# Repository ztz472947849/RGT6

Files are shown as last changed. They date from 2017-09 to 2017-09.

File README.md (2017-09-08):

# Embedded Glue

A minimal system runs MicroPython using STM32F405RGT6

Designed in KiCAD, free to use in any application.

# Pics

PCB preview in KiCAD
</br>

</br>
Actual PCB
</br>

</br>
And the size of its stencil
</br>


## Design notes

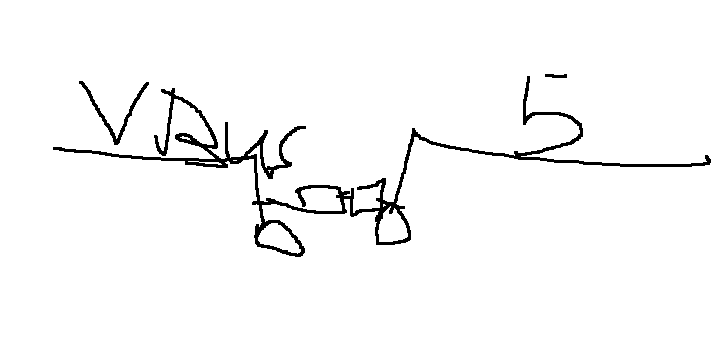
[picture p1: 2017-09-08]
RGT6_core_module/vbus.png

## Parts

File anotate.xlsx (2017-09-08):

sch | CPU | function | drop
j1 |  | a3v3 | C6 | uart/adc
j2 |  | usb_otg | C7
j3 |  | IO | A0 | uart
j4 |  | gnd | A1
j5 |  | vbus | A4 | SPI/DAC
j6 |  | 3v3 | A5
j7 |  | sd | A6
j8 |  | sd | A7
j9 |  | sd | pybaord X area bottom
j10 |  | sd | C4 | ADC only
j11 |  | IO | C5
j12 |  | IO | B0
j13 |  | IO | B1
j14 |  | boot0
j15 |  | boot1
j16 |  | adc
j17 |  | x
j18 |  | sd
j19 |  | sd
j20 |  | adc
j21 |  | adc
j22 |  | adc
j23 |  | IO
j24 |  | IO
j25 |  | SCL1
j26 |  | SDA1
j27 |  | SCL2
j28 |  | SDA2
j29 |  | IO
j30 |  | IO
j31 |  | uart TX
j32 |  | uart RX
j33 |  | uart2 TX
j34 |  | uart2 RX
j35 |  | uart3 TX
j36 |  | uart3 RX
j37 |  | DAC
j38 |  | DAC
j39 |  | IO
j40 |  | IO
j41 |  | sd
j42 |  | jtag
j43 |  | jtag
j44 |  | jtag
j45 |  | IO

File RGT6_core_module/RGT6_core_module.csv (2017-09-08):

Reference | Value | Footprint | general search | backup link
U1 | STM32F405RGTx | Housings_QFP:LQFP-64_10x10mm_Pitch0.5mm | http://uk.rs-online.com/web/p/microcontrollers/7468217/ | http://uk.farnell.com/search?st=STM32F405RGT
R2 | 100k | Resistors_SMD:R_0603 | http://uk.farnell.com/yageo/rc0603fr-07100kl/res-thick-film-100k-1-0-1w-0603/dp/2133868
C5 | 2u2 | Capacitors_SMD:C_0603 | http://uk.farnell.com/c/passive-components/capacitors/ceramic-capacitors/smd-ceramic-multilayer-mlcc-capacitors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
C6 | 2u2 | Capacitors_SMD:C_0603 | ¡ü
Y1 | 8Mhz | Crystals:Crystal_SMD_0603-2pin_6.0x3.5mm | http://uk.farnell.com/w/c/crystals-oscillators/crystals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
C3 | 18p | Capacitors_SMD:C_0603 | http://uk.farnell.com/multicomp/mc0603n180j500ct/cap-mlcc-c0g-np0-18pf-50v-0603/dp/1759056
C4 | 18p | Capacitors_SMD:C_0603 | ¡ü
L1 | 1k | Inductors_SMD:L_0603 | http://uk.farnell.com/c/passive-components/emc-rfi-suppression/ferrites-ferrite-assortments/ferrite-beads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
C8 | 100n | Capacitors_SMD:C_0603 | http://uk.farnell.com/walsin/0603b104k500ct/capacitor-mlcc-x7r-0-1uf-50v-0603/dp/2496834
C7 | 4u7 | Capacitors_SMD:C_0603 | http://uk.farnell.com/yageo/cc0603mrx5r5bb475/ceramic-capacitor-4-7uf-6-3v-x5r/dp/1817928
R7 | 100k | Resistors_SMD:R_0603 | http://uk.farnell.com/yageo/rc0603fr-07100kl/res-thick-film-100k-1-0-1w-0603/dp/2133868
SW1 | SW_Push | Buttons_Switches_SMD:SW_SPST_B3U-1000P | https://www.omron.com/ecb/products/pdf/en-b3u.pdf
R8 | 4k7 | Resistors_SMD:R_0603 | http://uk.farnell.com/w/c/passive-components/resistors-fixed-value/chip-smd-resistors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
R9 | 4k7 | Resistors_SMD:R_0603 | ¡ü
R10 | 4k7 | Resistors_SMD:R_0603 | ¡ü
R11 | 4k7 | Resistors_SMD:R_0603 | ¡ü
R12 | 4k7 | Resistors_SMD:R_0603 | ¡ü
J2 | USB_OTG | Connectors_USB:USB_Micro-B_Vertical_Molex | http://uk.farnell.com/global-connector-technology/usb3105-30-a/micro-usb-2-0-type-ab-receptacle/dp/2293775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
R4 | 560 | Resistors_SMD:R_0603 | http://uk.farnell.com/w/c/passive-components/resistors-fixed-value/chip-smd-resistors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
R5 | 22 | Resistors_SMD:R_0603 | http://uk.farnell.com/w/c/passive-components/resistors-fixed-value/chip-smd-resistors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
R6 | 22 | Resistors_SMD:R_0603 | ¡ü
R3 | 560 | Resistors_SMD:R_0603 | http://uk.farnell.com/w/c/passive-components/resistors-fixed-value/chip-smd-resistors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
Y2 | 32.768khz | Crystals:Crystal_SMD_0603-2pin_6.0x3.5mm | http://uk.farnell.com/c/crystals-oscillators/crystals?frequency-nom=32.768khz
C1 | 2p2 | Capacitors_SMD:C_0603 | http://uk.farnell.com/multicomp/mcmt18n2r2c160ct/cap-mlcc-c0g-np0-2-2pf-16v-0603/dp/1856096
C2 | 2p2 | Capacitors_SMD:C_0603 | ¡ü
D1 | D1 | ceremic diode | http://uk.farnell.com/c/semiconductors-discretes/diodes/small-signal-diodes
 |  | WS2812B | https://item.taobao.com/item.htm?id=43732789425&ns=1&abbucket=16
R1 | 300ohm | R 0603 | http://uk.farnell.com/w/c/passive-components/resistors-fixed-value/chip-smd-resistors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
R | 300ohm | R 0603 | ¡ü
U2 | MCP1703A-4002_SOT23 | TO_SOT_Packages_SMD:SOT-23 | not found on Farnell/RS
C9 | 1uf | Capacitors_SMD:C_0603 | http://uk.farnell.com/w/c/passive-components/capacitors/ceramic-capacitors/prl/results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
R13 | 220 | Resistors_SMD:R_0603 | http://uk.farnell.com/w/c/passive-components/resistors-fixed-value/chip-smd-resistors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

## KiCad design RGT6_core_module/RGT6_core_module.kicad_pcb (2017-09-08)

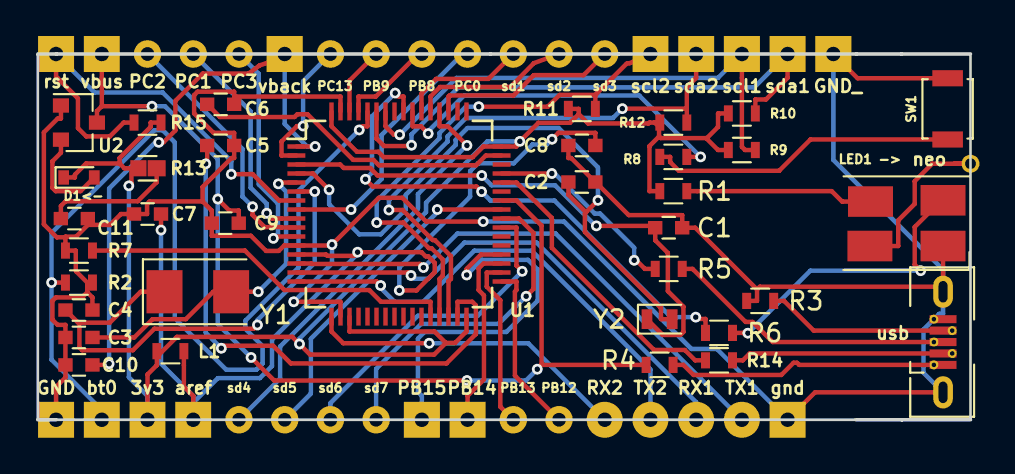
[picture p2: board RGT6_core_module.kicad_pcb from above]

Board: 2 copper layers, 51.8 x 20.3 mm, 71 parts (0 on the bottom side), 54 nets.

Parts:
3v3: CONN_01X01_FEMALE; SolderWirePad_single_0-8mmDrill
C1, C2: 2p2; C_0603
C3, C4: 18p; C_0603
C5, C6: 2u2; C_0603
C7: 4u7; C_0603
C8: 100n; C_0603
C9: 1uF; C_0603
C10, C11: 100nF; C_0603
D1<-: DIODE; D_0603
GND: GND; SolderWirePad_single_0-8mmDrill
GND_: GND; SolderWirePad_single_0-8mmDrill
L1: 1k; L_0603
LED1 ->: WS2812B; ws2812_big-pad
PB8, PB9, PB12: CONN_01X01_FEMALE; testpoint
PB13, PB14, PB15: jtag; testpoint
PC0, PC1, PC2, PC3: ADCs; testpoint
PC13: do not use; testpoint
R1, R14: 300; R_0603
R2, R7: 100k; R_0603
R3, R4: 560; R_0603
R5, R6: 22; R_0603
R8, R9, R10, R11, R12, R15: 4k7; R_0603
R13: 220; R_0603_short
RX1: uart4 RX; SolderWirePad_single_0-8mmDrill
RX2: usart RX; SolderWirePad_single_0-8mmDrill
SW1: SW_Push; SW_SPST_B3U-1000P
TX1: uart4 TX; SolderWirePad_single_0-8mmDrill
TX2: usart TX; SolderWirePad_single_0-8mmDrill
U1: STM32F405RGTx; LQFP-64_10x10mm_Pitch0.5mm
U2: MCP1703A-4002_SOT23; SOT-23
Y1: 8Mhz; Crystal_SMD_5032-2pin_5.0x3.2mm
Y2: 32.768khz; Crystal_SMD_2012-2pin_2.0x1.2mm
aref: a3v3; testpoint
bt0: CONN_01X01_FEMALE; SolderWirePad_single_0-8mmDrill
gnd: GND; SolderWirePad_single_0-8mmDrill
neo: neo_out; SolderWirePad_single_0-8mmDrill
rst: CONN_01X01_FEMALE; SolderWirePad_single_0-8mmDrill
scl1, scl2: CONN_01X01_FEMALE; SolderWirePad_single_0-8mmDrill
sd1, sd2, sd3, sd4, sd5, sd6, sd7: CONN_01X01_FEMALE; testpoint
sda1, sda2: CONN_01X01_FEMALE; SolderWirePad_single_0-8mmDrill
usb: USB_OTG; my_usb
vback: CONN_01X01_FEMALE; SolderWirePad_single_0-8mmDrill
vbus: CONN_01X01_FEMALE; SolderWirePad_single_0-8mmDrill

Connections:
3.3v: 3v3.1, D1<-.1, L1.2, R1.1, R9.1, R10.1, R11.1, R12.1, R13.1, R15.2, U1.19, U1.32, U1.48, U1.64
A3v3: C7.2, C8.2, L1.1, U1.13, aref.1
D+: R5.1, U1.45
D-: R6.1, U1.44
unnamed: C1.1, U1.3, Y2.1
unnamed: C2.1, U1.4, Y2.2
unnamed: C3.2, U1.5, Y1.2
unnamed: C4.1, U1.6, Y1.1
unnamed: C5.1, U1.31
unnamed: C6.1, U1.47
unnamed: D1<-.2, U2.2
unnamed: R4.2, usb.1
unnamed: R6.2, usb.2
unnamed: R5.2, usb.3
unnamed: R3.1, usb.4
unnamed: LED1 ->.1, R1.2
unnamed: LED1 ->.4, R14.1
unnamed: R8.1, SW1.1
unnamed: R8.2, U1.55
PA0: TX1.1, U1.14
PA1: RX1.1, U1.15
PA2: TX2.1, U1.16
PA3: RX2.1, U1.17
PA8_sd: U1.41, sd5.1
PB4: R14.2, U1.56
PB8: PB8.1, U1.61
PB9: PB9.1, U1.62
PB12: PB12.1, U1.33
PB13: PB13.1, U1.34
PB14: PB14.1, U1.35
PB15: PB15.1, U1.36
PC0: PC0.1, U1.8
PC1: PC1.1, U1.9
PC2: PC2.1, U1.10
PC3: PC3.1, U1.11
PC8_sd: U1.39, sd6.1
PC9_sd: U1.40, sd7.1
PC10_sd: U1.51, sd3.1
PC11_sd: U1.52, sd4.1
PC12_sd: U1.53, sd2.1
PC13: PC13.1, U1.2
PD2_sd: U1.54, sd1.1
SCL1: R9.2, U1.58, scl1.1
SCL2: R11.2, U1.29, scl2.1
SDA1: R10.2, U1.59, sda1.1
SDA2: R12.2, U1.30, sda2.1
boot0: R2.1, U1.60, bt0.1
boot1: R7.2, U1.28
gnd: C1.2, C2.2, C3.1, C4.2, C5.2, C6.2, C7.1, C8.1, C9.1, C10.2, C11.2, GND.1, GND_.1, LED1 ->.3, R2.2, R3.2, R7.1, SW1.2, U1.12, U1.18, U1.63, U2.1, gnd.1, usb.5, usb.6
neo_out: LED1 ->.2, neo.1
rst: R15.1, U1.7, rst.1
v-battery: C11.1, R13.2
vbackup: C10.1, U1.1, vback.1
vbus: C9.2, R4.1, U1.42, U2.3, vbus.1

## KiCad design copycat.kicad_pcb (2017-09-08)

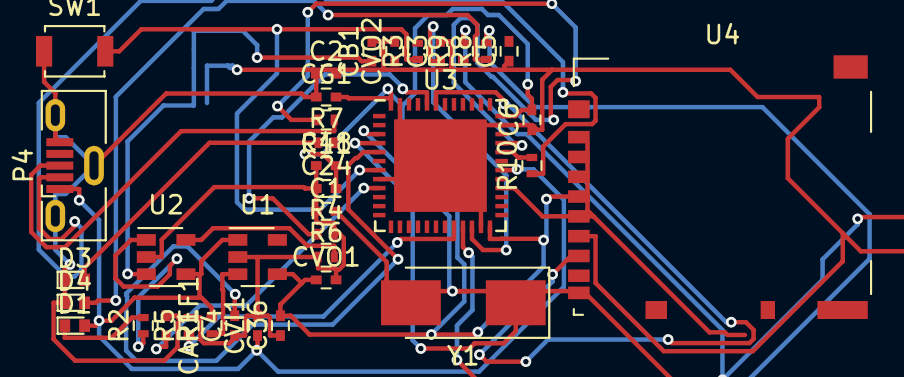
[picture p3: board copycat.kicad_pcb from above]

Board: 2 copper layers, 37 parts (1 on the bottom side), 30 nets.

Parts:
C1, C2: 2.2pF; C_0402
C3: 2.2uF; C_0402
C4, C5: 18pF; C_0402
C6: 4.7uF; C_0402
C24, C36, C48: 0.1uF; C_0402
CAREF1: 0.1uF; C_0402
CB1: 10uF; C_0402
CG1: 4.7uF; C_0402
CVI1: 10uF; C_0402
CVO1: 10uF; C_0402
CVO2: 1uF; C_0402
D1: ORANGE; LED_0402
D3: RED; LED_0402
D4: BLUE; LED_0402
P2: CONN_01X02; JST_PH_S2B-PH-SM4-TB_02x2.00mm_Angled
P4: USB_OTG; USB_Micro-B_Vertical_Molex-105133-0001
R1, R4, R5: 100k; R_0402
R2: 1k; R_0402
R3: 4k7; R_0402
R6, R9: 10k; R_0402
R7: 560; R_0402
R8: 220; R_0402
R10, R11: 22; R_0402
SW1: RST; SW_SPST_B3U-1000P
U1: SPX3819; SOT-23-5
U2: MCP73811T-420I/OT; SOT-23-5
U3: STM32F411CEUx; QFN-48-1EP_7x7mm_Pitch0.5mm
U4: MicroSD_SPI_CD; microSD_Card_Receptacle_Hirose_DM3AT-SF-PEJM5
Y1: 32.768Hz; Crystal_SMD_0603-2pin_6.0x3.5mm_HandSoldering

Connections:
+3V3: C6.2, C24.2, C36.2, C48.2, CG1.2, CVO1.1, CVO2.1, R3.2, R9.1, U1.4, U3.24, U3.36, U3.48, U4.4
AREF: CAREF1.2, U3.9
BOOT0: R4.1, U3.44
CD: R9.2, U4.9
DI: U3.16, U4.3
DO: U3.43, U4.7
EN: R1.1, U1.3
GND: C1.1, C2.1, C3.2, C4.1, C5.1, C6.1, C24.1, C36.1, C48.1, CAREF1.1, CB1.2, CG1.1, CVI1.2, CVO1.2, CVO2.2, D3.1, D4.1, P2.1, P4.5, P4.6, R4.2, R5.2, R6.1, SW1.1, U1.2, U2.2, U3.8, U3.23, U3.35, U3.47, U3.49, U4.6
IO0: R8.2, U3.21
IO1: R7.2, U3.27
unnamed: C3.1, U3.22
unnamed: D1.1, R2.2
unnamed: D3.2, R7.1
unnamed: D4.2, R8.1
unnamed: P4.2, R10.1
unnamed: P4.3, R11.1
unnamed: P4.4, U3.31
unnamed: R2.1, U2.1
unnamed: R5.1, U3.20
unnamed: R6.2, U2.5
unnamed: R10.2, U3.32
unnamed: R11.2, U3.33
OSC32IN: C1.2, U3.3, Y1.2
OSC32OUT: C2.2, U3.4, Y1.1
OSCIN: C4.2, U3.5
OSCOUT: C5.2, U3.6
RST: R3.1, SW1.2, U3.7
SCLK: U3.28, U4.5
VBAT: CB1.1, P2.2, U2.3
VBUS: CVI1.1, D1.2, P4.1, R1.2, U1.1, U2.4, U3.30

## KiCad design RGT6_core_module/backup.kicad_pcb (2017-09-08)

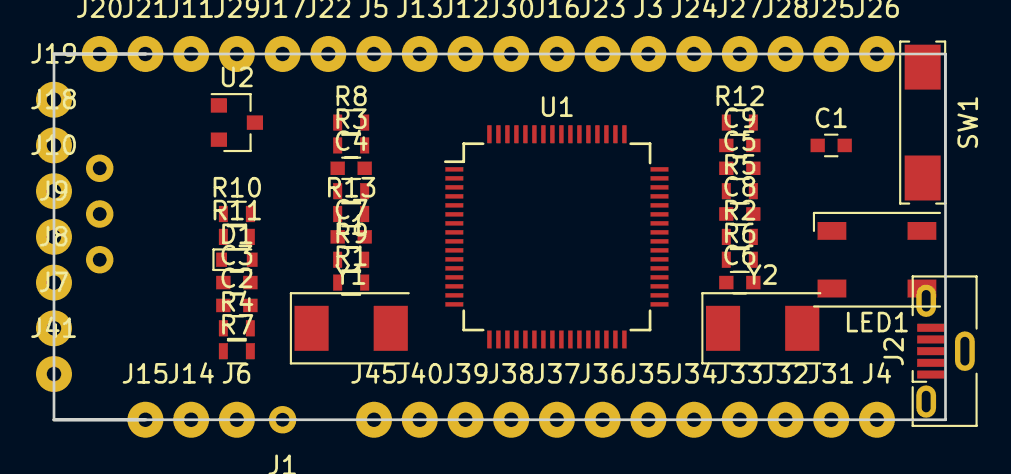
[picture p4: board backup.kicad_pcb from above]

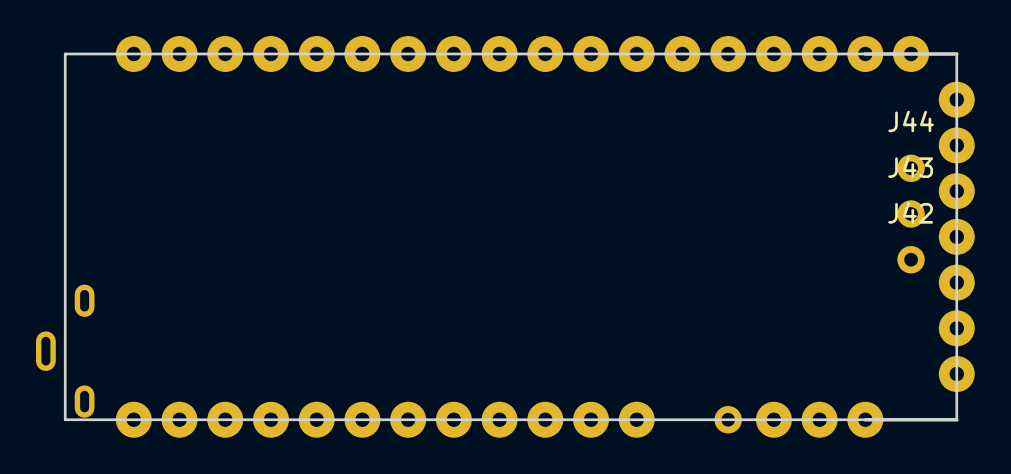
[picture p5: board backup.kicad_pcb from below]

Board: 2 copper layers, 49.5 x 20.3 mm, 75 parts (3 on the bottom side), 58 nets, no tracks yet.

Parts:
C1, C2: 2p2; C_0603
C3, C4: 18p; C_0603
C5, C6: 2u2; C_0603
C7: 4u7; C_0603
C8: 100n; C_0603
C9: C; C_0603
D1: DIODE; D_0603
J1: a3v3; testpoint
J2: USB_OTG; USB_Micro-B_Vertical_Molex-105133-0001
J3, J5, J6, J7, J8, J9, J10, J11, J12, J13, J14, J15, J18, J19, J23, J24, J25, J26, J27, J28, J41, J45: CONN_01X01_FEMALE; SolderWirePad_single_0-8mmDrill
J4: GND; SolderWirePad_single_0-8mmDrill
J16, J20, J21, J22: ADCs; SolderWirePad_single_0-8mmDrill
J17: do not use; SolderWirePad_single_0-8mmDrill
J29, J30, J39, J40: IOs; SolderWirePad_single_0-8mmDrill
J31, J35: usart TX; SolderWirePad_single_0-8mmDrill
J32, J36: usart RX; SolderWirePad_single_0-8mmDrill
J33: uart4 TX; SolderWirePad_single_0-8mmDrill
J34: uart4 RX; SolderWirePad_single_0-8mmDrill
J37, J38: DACs; SolderWirePad_single_0-8mmDrill
J42, J43, J44: jtag; testpoint
L1: 1k; L_0603
LED1: WS2812B; LED_WS2812B-PLCC4
R1: 300; R_0603
R2, R7: 100k; R_0603
R3, R4: 560; R_0603
R5, R6: 22; R_0603
R8, R9, R10, R11, R12: 4k7; R_0603
R13: 220; R_0603
SW1: SW_Push; SW_SPST_REED_CT05-XXXX-J1
U1: STM32F405RGTx; LQFP-64_10x10mm_Pitch0.5mm
U2: MCP1703A-4002_SOT23; SOT-23
Y1: 8Mhz; Crystal_SMD_0603-2pin_6.0x3.5mm
Y2: 32.768khz; Crystal_SMD_0603-2pin_6.0x3.5mm

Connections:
3.3v: D1.1, J6.1, L1.2, R1.1, R9.1, R10.1, R11.1, R12.1, R13.1, U1.7, U1.19, U1.32, U1.48, U1.64
A3v3: C7.2, C8.2, J1.1, L1.1, U1.13
D+: R5.1, U1.45
D-: R6.1, U1.44
unnamed: C1.1, U1.3, Y2.1
unnamed: C2.1, U1.4, Y2.2
unnamed: C3.2, U1.5, Y1.2
unnamed: C4.1, U1.6, Y1.1
unnamed: C5.1, U1.31
unnamed: C6.1, U1.47
unnamed: D1.2, U2.2
unnamed: J2.1, R4.2
unnamed: J2.2, R6.2
unnamed: J2.3, R5.2
unnamed: J2.4, R3.1
unnamed: LED1.1, R1.2
unnamed: R8.1, SW1.1
unnamed: R8.2, U1.55
PA0: J33.1, U1.14
PA1: J34.1, U1.15
PA2: J35.1, U1.16
PA3: J36.1, U1.17
PA4: J37.1, U1.20
PA5: J38.1, U1.21
PA6: J39.1, U1.22
PA7: J40.1, U1.23
PA8_sd: J41.1, U1.41
PB4: LED1.4, U1.56
PB8: J11.1, J23.1, U1.61
PB9: J12.1, J24.1, U1.62
PB12: J13.1, U1.33
PB13: J42.1, U1.34
PB14: J43.1, U1.35
PB15: J44.1, U1.36
PC0: J16.1, U1.8
PC1: J20.1, U1.9
PC2: J21.1, U1.10
PC3: J22.1, U1.11
PC4: J29.1, U1.24
PC5: J30.1, U1.25
PC6: J31.1, U1.37
PC7: J32.1, U1.38
PC8_sd: J8.1, U1.39
PC9_sd: J9.1, U1.40
PC10_sd: J10.1, U1.51
PC11_sd: J19.1, U1.52
PC12_sd: J18.1, U1.53
PC13: J17.1, U1.2
PD2_sd: J7.1, U1.54
SCL1: J25.1, R9.2, U1.58
SCL2: J27.1, R11.2, U1.29
SDA1: J26.1, R10.2, U1.59
SDA2: J28.1, R12.2, U1.30
boot0: J14.1, R2.1, U1.60
boot1: J15.1, R7.2, U1.28
gnd: C1.2, C2.2, C3.1, C4.2, C5.2, C6.2, C7.1, C8.1, C9.1, J2.5, J2.6, J4.1, LED1.3, R2.2, R3.2, R7.1, SW1.2, U1.12, U1.18, U1.63, U2.1
vbat: J5.1, R13.2, U1.1
vbus: C9.2, R4.1, U1.42, U2.3
